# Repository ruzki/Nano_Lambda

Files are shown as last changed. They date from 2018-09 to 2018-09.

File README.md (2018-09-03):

# Nano_Lambda
Wideband Lambda shield for Arduino Nano <br />
License <br />

<br />
KiCad Project about a Wideband Lambda shield for the Arduino Nano <br />
Analog output signal can be generate via 2x MCP4725 or an PWM driven Op-Amp <br />

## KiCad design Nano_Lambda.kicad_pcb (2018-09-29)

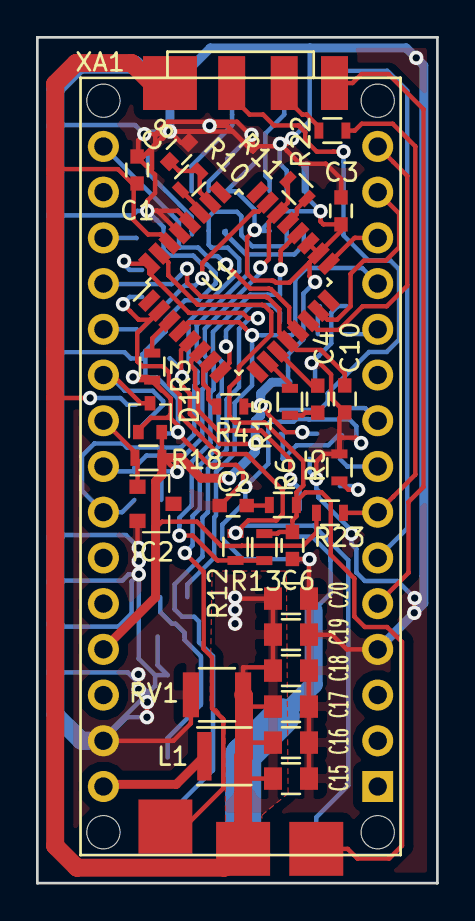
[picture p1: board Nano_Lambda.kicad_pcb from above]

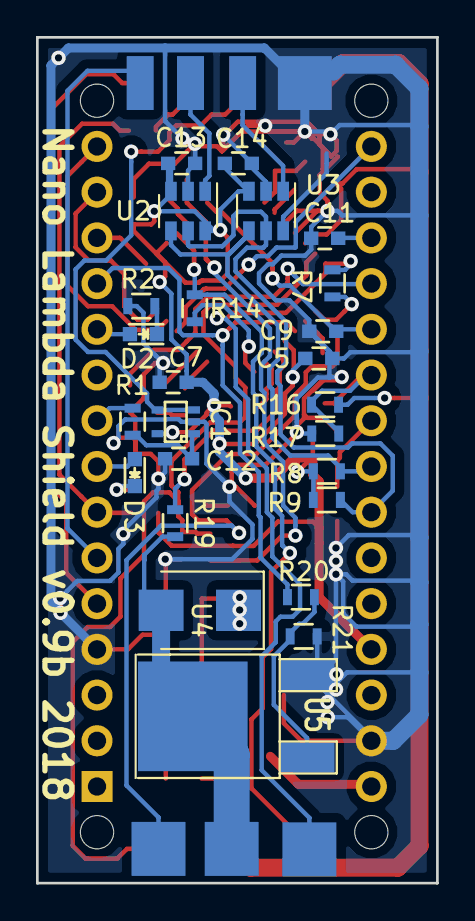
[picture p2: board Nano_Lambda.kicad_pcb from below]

Board: 2 copper layers, 22.2 x 47.0 mm, 70 parts (32 on the bottom side), 47 nets.

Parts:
C1, C3, C4, C5, C7, C8, C11, C12, C13, C14: 100n; C_0603
C2: 2.2n; C_0603
C6: C; C_0603
C9, C10: 33n; C_0603
C15, C16, C17, C18, C20: 22µF 25V; C_0805
C19: 6x 22µF 25V; C_0805
D1: BAT54S; SOT-323
D2: Blue; LED-0603
D3: red; LED-0603
IC1: LMV321?M5; SC-70-5
IC2: LM4041DBZ; SOT-23
J1: +12_IN; 3x3_PAD
J2: GND; 3x3_PAD
J3: +12V_NL; 3x3_PAD
J4: IP; 3x3_PAD
J5: UN; 3x3_PAD
J6: NL_HEATER; 3x3_PAD
J7: IA; 3x3_PAD
J8: VM; 3x3_PAD
J9: PD2; 1.5x3_PAD
J10: PD3; 1.5x3_PAD
J11: GP3; 1.5x3_PAD
J12: DAC1; 1.5x3_PAD
J13: DAC2; 1.5x3_PAD
J14: Out1; 1.5x3_PAD
L1: 22µH; Inductor_Taiyo-Yuden_MD-3030
R1, R3, R4, R8, R9, R17: 10k; R_0603
R2, R5: 1k; R_0603
R6: R; R_0603
R7: 61.9R; R_0603
R10, R13, R21, R23: 100k; R_0603
R11, R20, R22: 4.7k; R_0603
R12: 470k; R_0603
R14: 300R / 1%; R_0603
R15: 31.6k / 1%; R_0603
R16, R18: 39k; R_0603
R19: 6.8k; R_0603
RV1: Varistor; R_1210
U1: CJ125_32; LQFP-32_7x7mm_Pitch0.8mm
U2, U3: MCP4725; SOT-23-6
U4: MURS120; SMB_Standard
U5: IRLZ44; DPAKGDS
XA1: Arduino_Nano_Socket

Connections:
+5V: C3.1, C5.1, C7.2, C13.2, C14.2, D1.2, IC1.5, R4.2, R8.2, R9.2, R18.2, R23.1, U1.5, U1.18, U1.19, U2.3, U2.6, U3.3, XA1.5V
/+12V_NL: C1.1, C15.2, C16.2, C17.2, C18.2, C19.2, C20.2, J1.1, J3.1, L1.2, R16.2, RV1.1, U1.30, U4.1
/BRV: D1.3, R16.1, R17.2, XA1.A2
/CM: C4.2, R15.1
/DAC1: J12.1, U3.1
/DAC2: J13.1, U2.1
/DIAHD: R19.2, U1.6
/DIAHG: R20.2, U1.4, XA1.D9
/GP3: J11.1, R22.1
/IA: J7.1, R7.2, R12.1, U1.2
/IP: J4.1, R7.1, U1.32
/LED_1: D2.2, XA1.D8
/LED_2: D3.2, XA1.D5
/LS_MISO: U1.14, XA1.D12
/LS_MOSI: U1.15, XA1.D11
/LS_SCK: U1.13, XA1.D13
/LS_SS: U1.17, XA1.D10
/NL_HEATER: J6.1, R19.1, U4.2, U5.D
/Out1: IC1.3, IC1.4, J14.1
/PD2: J9.1, XA1.D2
/PD3: J10.1, XA1.D3
/RM: R15.2, U1.10
/RS: R14.1, U1.8
/SCL: R9.1, U2.5, U3.5, XA1.A5
/SDA: R8.1, U2.4, U3.4, XA1.A4
/UA: C9.1, U1.23, XA1.A1
/UN: C6.1, J5.1, R6.1, R13.1, U1.31
/UR: C10.1, U1.12, XA1.A0
/VM: J8.1, R14.2, U1.20
/V_REF: IC2.1, R18.1, XA1.A3
/WBL: R1.2, XA1.D6
GND: C1.2, C2.2, C3.2, C5.2, C6.2, C7.1, C8.1, C9.2, C10.2, C11.2, C12.1, C13.1, C14.1, C15.1, C16.1, C17.1, C18.1, C19.1, C20.1, D1.1, IC1.2, IC2.2, J2.1, R2.1, R3.2, R5.1, R17.1, R21.1, RV1.2, U1.28, U1.29, U2.2, U3.2, U3.6, U5.S, XA1.GND1, XA1.GND2
unnamed: C2.1, R6.2
unnamed: C4.1, U1.11
unnamed: C8.2, R10.1, U1.26
unnamed: C11.1, XA1.AREF
unnamed: C12.2, IC1.1, R1.1
unnamed: D2.1, R2.2
unnamed: D3.1, R5.2
unnamed: L1.1, XA1.VIN
unnamed: R3.1, U1.3
unnamed: R4.1, U1.7
unnamed: R10.2, U1.27
unnamed: R11.1, R12.2, R13.2, U1.22
unnamed: R11.2, U1.21
unnamed: R20.1, R21.2, U5.G
unnamed: R22.2, R23.2, XA1.D4

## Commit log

2018-09-03 Initial commit
    Version 0.9
    [Nano_Lambda-B.Cu.gbl, Nano_Lambda-B.Mask.gbs, Nano_Lambda-B.Paste.gbp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]
2018-09-13 Change to Version 0.9b
    Changed wrong CJ125 Footprint to Footprint with 0.8mm pitch.
    [Nano_Lambda.kicad_pcb, Nano_Lambda.sch]
2018-09-15 Minor changes and new gerber files
    [Nano_Lambda-B.Cu.gbl, Nano_Lambda-B.Mask.gbs, Nano_Lambda-B.Paste.gbp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]
2018-09-16 Fabrication version 0.9b
    Fabrication version 0.9b
    [Nano_Lambda-B.Cu.gbl, Nano_Lambda-B.Mask.gbs, Nano_Lambda-B.Paste.gbp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]
2018-09-29 Diode u4 wrong direction
    Swapped pin numbers on Diode MURS120 symbol in schematic. Changed pin 1
    to 2 and 2 to 1
    [Nano_Lambda.kicad_pcb]

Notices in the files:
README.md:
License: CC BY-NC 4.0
